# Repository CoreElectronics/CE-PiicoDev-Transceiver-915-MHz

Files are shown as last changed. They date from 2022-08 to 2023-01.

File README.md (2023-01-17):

# PiicoDev® Transceiver

This is the repo for the Core Electronics [PiicoDev Transceiver](https://core-electronics.com.au/catalog/product/view/sku/CE08757).

## License
This project is open source - please review the LICENSE.md file for further licensing information.

If you have any technical questions, or concerns about licensing, please contact technical support on the [Core Electronics forums](https://forum.core-electronics.com.au/).

*\"PiicoDev\" and the PiicoDev logo are trademarks of Core Electronics Pty Ltd.*

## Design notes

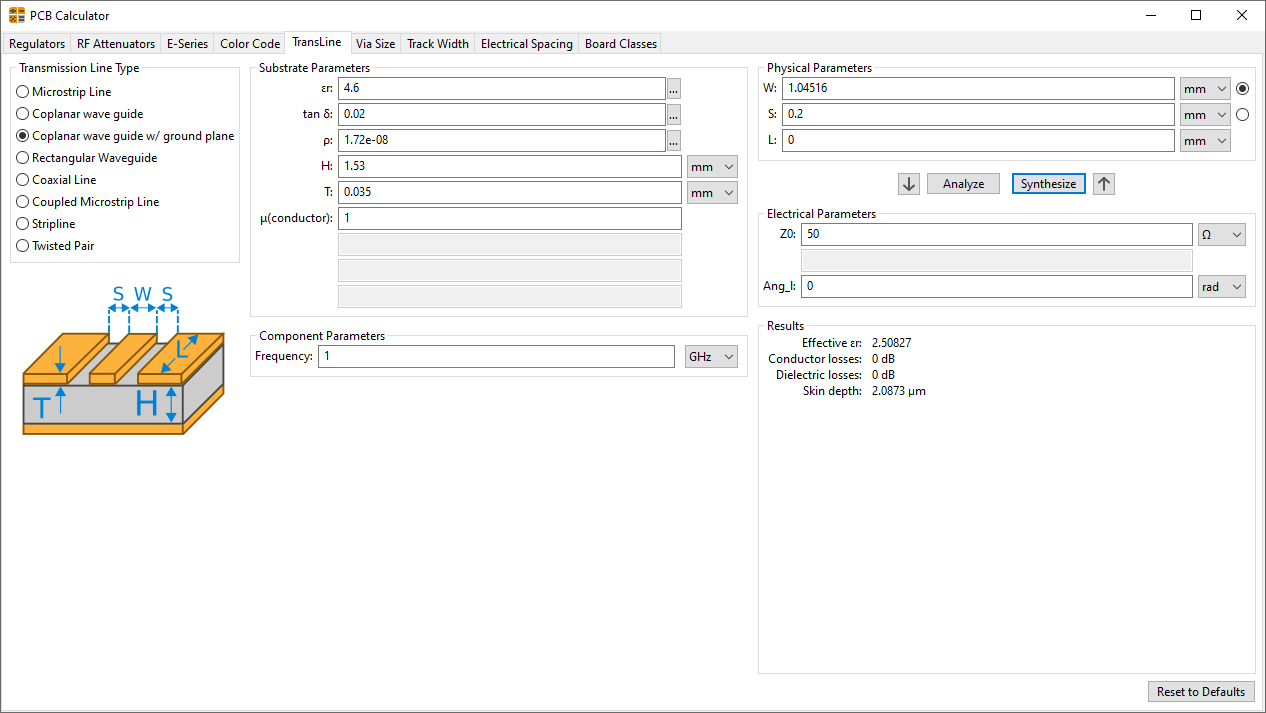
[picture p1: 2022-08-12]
Documents/PCB Calculator.png

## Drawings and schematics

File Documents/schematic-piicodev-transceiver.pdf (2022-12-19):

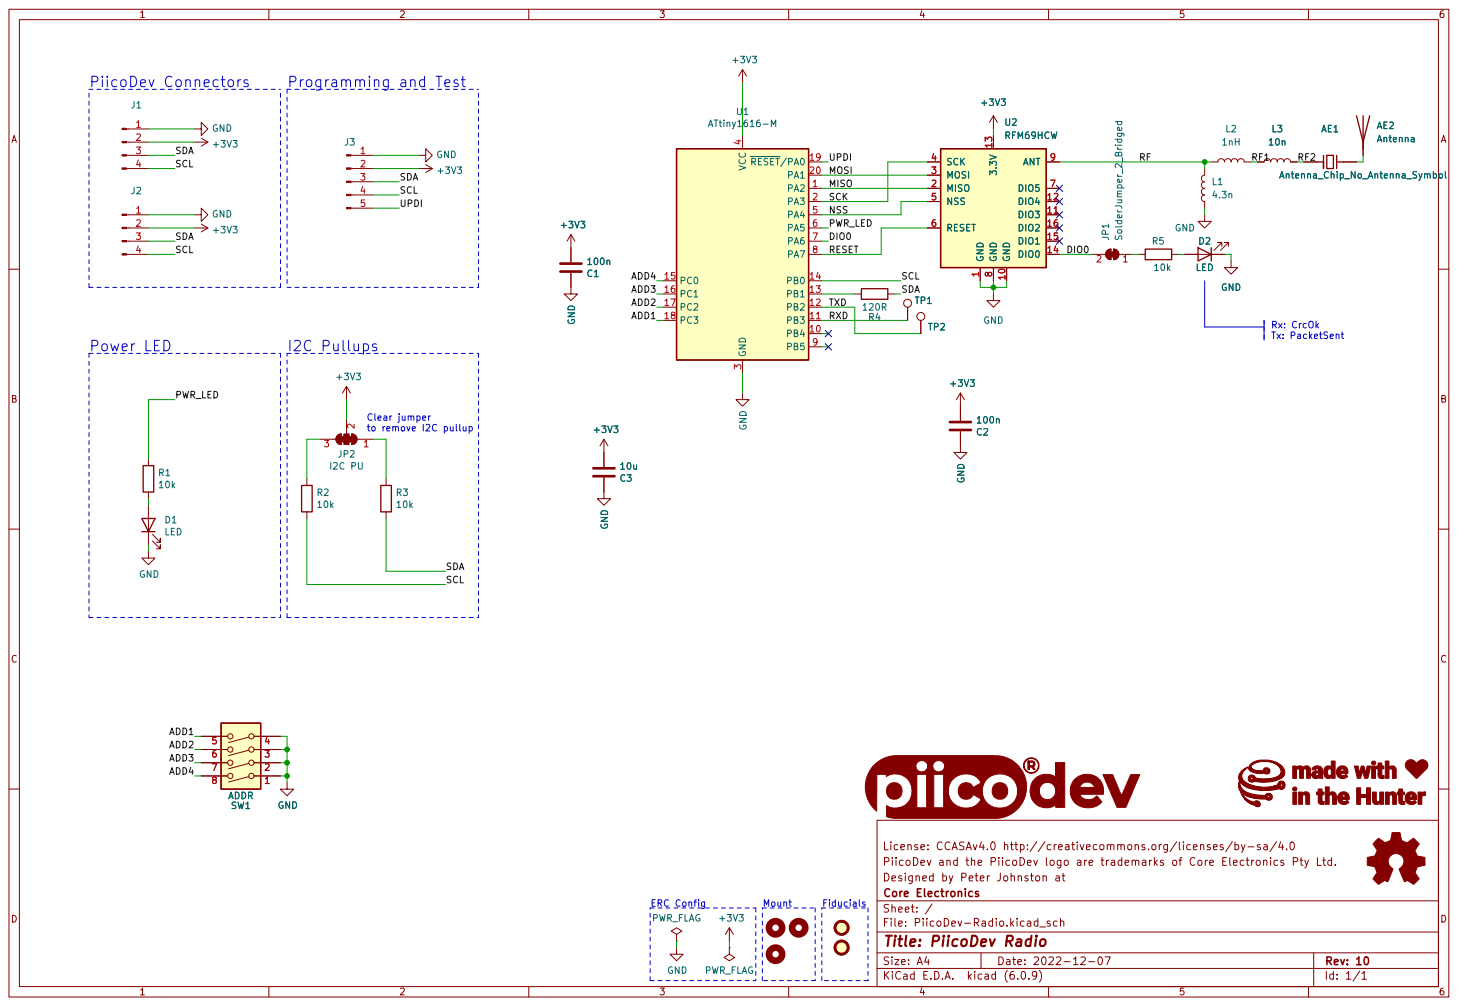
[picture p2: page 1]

1 GND 10 DIO3 11 DIO4 12 3.3V 13 DIO0 14 DIO1 15 DIO2 16 MISO 2 MOSI 3 SCK 4 NSS 5 RESET 6 DIO5 7 GND

Rx: CrcOk Tx: PacketSent SW1 ADDR

License: CCASAv4.0 http://creativecommons.org/licenses/by-sa/4.0
PiicoDev and the PiicoDev logo are trademarks of Core Electronics Pty Ltd.
File: PiicoDev-Radio.kicad_sch Sheet: / Core Electronics Designed by Peter Johnston at

Id: 1/1 Title: PiicoDev Radio

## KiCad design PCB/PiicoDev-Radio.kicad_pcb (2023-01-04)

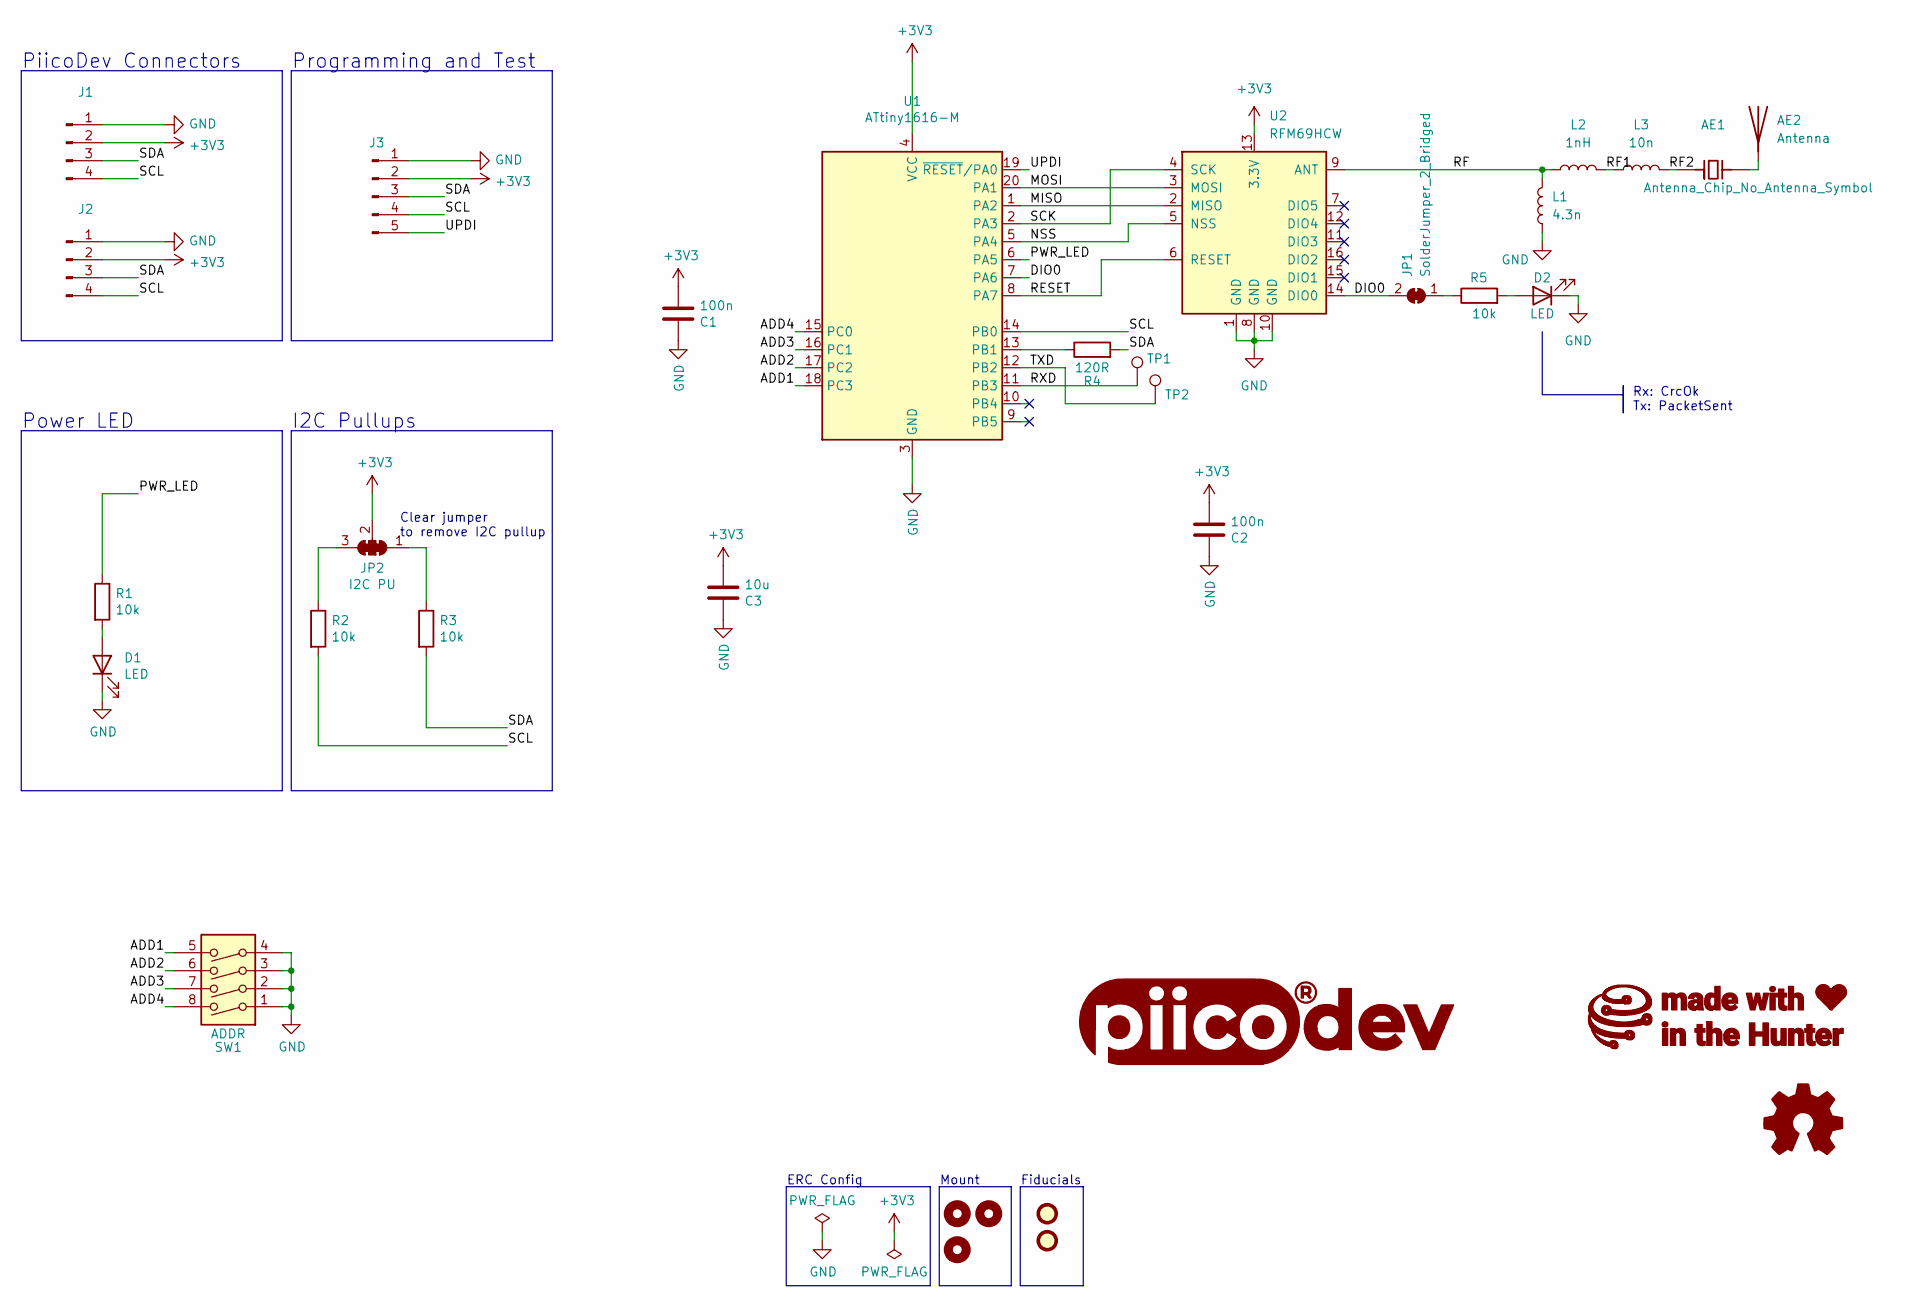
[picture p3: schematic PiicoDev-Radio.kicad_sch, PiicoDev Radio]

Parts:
AE1: Antenna_Chip_No_Antenna_Symbol; Antenna_Chip_TDK_ANT160920ST-1204A1
AE2: Antenna; PiicoDev_Radio_Antenna
C1, C2: 100n; C_0402_1005Metric
C3: 10u; C_0603_1608Metric
D1, D2: LED; LED_0603_1608Metric
FID1, FID2: Fiducial; Fiducial_1mm_Mask2mm
G1: LOGO_PiicoDev; piicodev_logo_14.2x3.4mm
G2: LOGO_CoreElectronics_no-text; CoreElectronics_logo_5mm_v2
G3: LOGO_made-with-love; piicodev_logo_14.2x3.4mm
H1, H2, H3: MountingHole; MountingHole_2.7mm_M2.5_PadClearance_1.2
J1, J2: JST_SH_SM04B-SRSS-TB_1x04-1MP_P1.00mm_Horizontal
J3: Conn_01x05_Male; TestPoint_Pad_D1.0mm_x05_Pattern1
JP1: SolderJumper_2_Bridged; SolderJumper-2_P1.3mm_Bridged_RoundedPad1.0x1.5mm
JP2: I2C PU; SolderJumper-3_P1.3mm_Closed_RoundedPad1.0x1.5mm_NumberLabe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
L1: 4.3n; L_0402_1005Metric
L2: 1nH; L_0402_1005Metric
L3: 10n; L_0402_1005Metric
LOGO1: Logo_Open_Hardware_Small; oshw
R1, R2, R3, R5: 10k; R_0402_1005Metric
R4: 120R; R_0402_1005Metric
SW1: ADDR; SW_DIP_x04_Slide_CHS-04A1
TP1, TP2: TestPoint; TestPoint_Pad_1.5x1.5mm
U1: ATtiny1616-M; VQFN-20-1EP_3x3mm_P0.4mm_EP1.7x1.7mm
U2: RFM69HCW; HOPERF_RFM69HCW_SMD

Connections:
+3V3: C1.2, C2.2, C3.2, J1.2, J2.2, J3.2, JP2.2 (C), U1.4 (VCC), U2.13 (3.3V)
/ADD1: SW1.5, U1.18 (PC3)
/ADD2: SW1.6, U1.17 (PC2)
/ADD3: SW1.7, U1.16 (PC1)
/ADD4: SW1.8, U1.15 (PC0)
/DIO0: JP1.2 (B), U1.7 (PA6), U2.14 (DIO0)
/MISO: U1.1 (PA2), U2.2 (MISO)
/MOSI: U1.20 (PA1), U2.3 (MOSI)
/NSS: U1.5 (PA4), U2.5 (NSS)
/PWR_LED: R1.1, U1.6 (PA5)
/RESET: U1.8 (PA7), U2.6 (RESET)
/RF: L1.2, L2.1, U2.9 (ANT)
/RF1: L2.2, L3.1
/RF2: AE1.4 (FEED), L3.2
/RXD: TP1.1, U1.11 (PB3)
/SCK: U1.2 (PA3), U2.4 (SCK)
/SCL: J1.4, J2.4, J3.4, R2.2, U1.14 (PB0)
/SDA: J1.3, J2.3, J3.3, R3.2, R4.2
/TXD: TP2.1, U1.12 (PB2)
/UPDI: J3.5, U1.19 (~RESET/PA0)
GND: C1.1, C2.1, C3.1, D1.1 (K), D2.1 (K), J1.1, J2.1, J3.1, L1.1, SW1.1, SW1.2, SW1.3, SW1.4, U1.3 (GND), U1.21 (GND), U2.1 (GND), U2.8 (GND), U2.10 (GND)
unnamed: AE1.1 (PCB_Trace), AE2.1 (A)
unnamed: D1.2 (A), R1.2
unnamed: D2.2 (A), R5.2
unnamed: JP1.1 (A), R5.1
unnamed: JP2.1 (A), R3.1
unnamed: JP2.3 (B), R2.1
unnamed: R4.1, U1.13 (PB1)

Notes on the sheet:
PiicoDev Connectors
I2C Pullups
Power LED
Rx: CrcOk Tx: PacketSent
Mount
Clear jumper to remove I2C pullup
Programming and Test
ERC Config
Fiducials

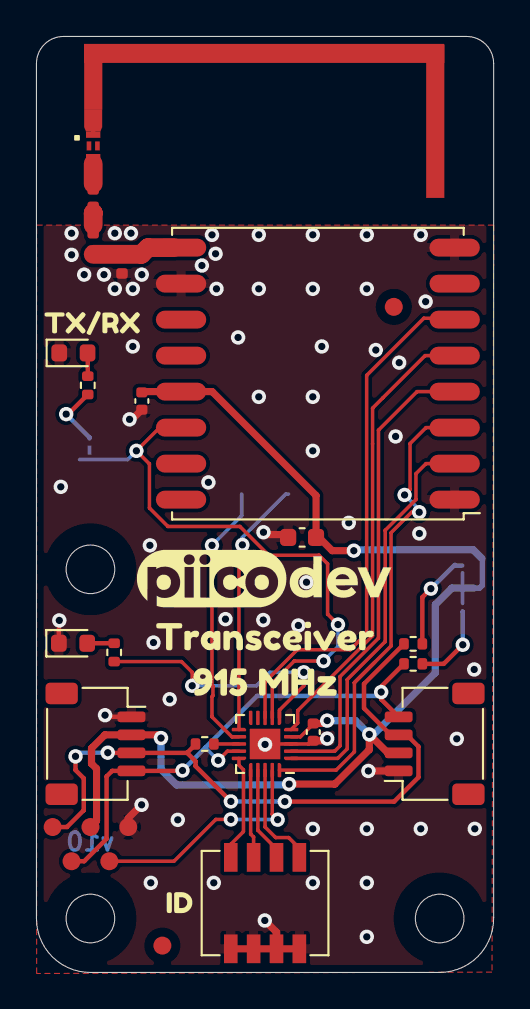
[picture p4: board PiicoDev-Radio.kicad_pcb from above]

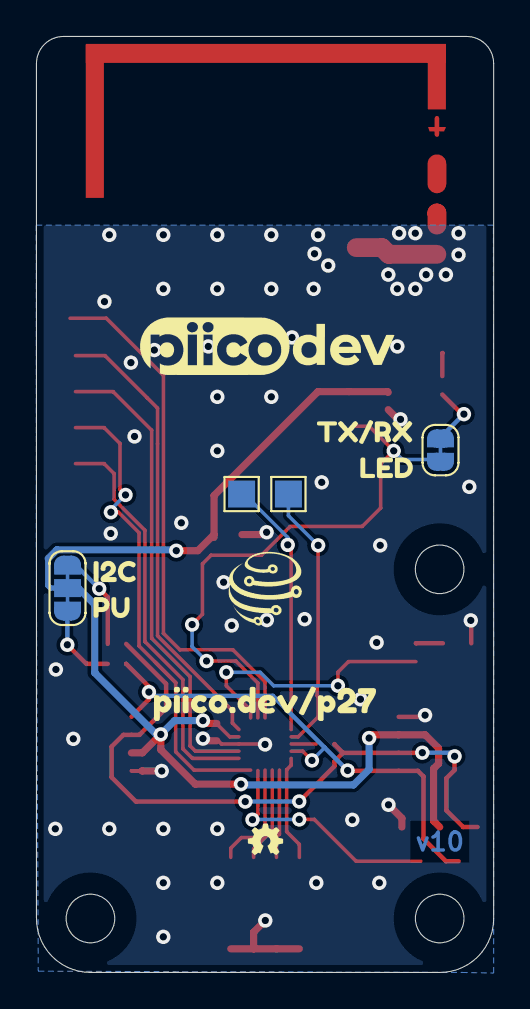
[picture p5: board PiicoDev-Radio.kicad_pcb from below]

Board: 2 copper layers, 25.4 x 52.0 mm, 41 parts (10 on the bottom side), 28 nets.

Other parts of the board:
kibuzzard-637C5B84: G***; kibuzzard-637C5B84
kibuzzard-637C5BCC: G***; kibuzzard-637C5BCC
kibuzzard-637C5BDE: G***; kibuzzard-637C5BDE
kibuzzard-637C5DFB: G***; kibuzzard-637C5DFB
kibuzzard-637C5EAE: G***; kibuzzard-637C5EAE
kibuzzard-637C5EDA: G***; kibuzzard-637C5EDA
kibuzzard-637C5F9F: G***; kibuzzard-637C5F9F

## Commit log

2022-08-11 Create KiCad project
    [PiicoDev-Radio.kicad_pcb, PiicoDev-Radio.kicad_sch]
2022-08-18 Basic design complete
    [PiicoDev-Radio.kicad_pcb, PiicoDev-Radio.kicad_sch]
2022-09-07 Add jumpers to allow external pull-up resistors
    [PiicoDev-Radio.kicad_pcb]
2022-11-10 Remove SMA and add PCB antenna
    [PiicoDev-Radio.kicad_pcb, PiicoDev-Radio.kicad_sch]
2022-11-16 Improve F.Fab layer
    [PiicoDev-Radio.kicad_pcb]
2022-11-17 Change R5 to 1k
    [PiicoDev-Radio.kicad_pcb, PiicoDev-Radio.kicad_sch]
2022-12-07 v10 Improve RFM69HCW footprint
    [PiicoDev-Radio.kicad_pcb, PiicoDev-Radio.kicad_sch]
2022-12-13 Update chip antenna footprint
    [PiicoDev-Radio.kicad_pcb, PiicoDev-Radio.kicad_sch]
2023-01-04 exclude artwork components from BOM + .pos files
    [PiicoDev-Radio.kicad_pcb]
2023-01-09 rename schematic pdf
